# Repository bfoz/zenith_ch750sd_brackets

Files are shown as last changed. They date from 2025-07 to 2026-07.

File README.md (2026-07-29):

# Zenith CH750 Super Duty Brackets

Custom brackets that can be used to improve wire, cable, and hose routing.

## Fabrication

The various online cut shops have different ordering processes so you'll need to consult their documentation. 

If you're familiar with FreeCAD's Sheet Metal Workbench you can try using the "Unfold" feature to generate the flattened drawing files to send to the shop. 
However, exporting to a STEP file seems to produce more consistent results.

NOTE: As of June 2025, the unfolded files don't work well with [Send Cut Send](https://sendcutsend.com); use the STEP files instead.

## Wing Trailing Edge Bracket

The stock kit doesn't use the space inside of the wing trailing edge skins for very much.
If your build uses that space for a fuel return hose, or for the pitot and AoA hoses, you can use these brackets to help keep everything organized.

The file `TrailingEdgeBracket.FCStd` is a FreeCAD file containing several different bracket designs meant for different configurations of wiring and hoses in the left wing. 

The part named `OutboardTrailingEdgeBracket` is intended to hold the wires that go out to the wingtips and the slats (if you have those). 
You can either use 4 of these brackets for each wing and replace the ziptie anchors that came in the kit, or you can use one for each wing just inboard of the joiner bracket in the rear spar.
If you have a fuel return hose from your engine (ULPower etc), you'll want to use at least one of these (inboard of the joiner plate but outboard of the fuel hose) to help hold the wires off of that hose.

For the right wing, which doesn't have Pitot or AoA tubes, you can use `OutboardTrailingEdgeBracket` for the inboard brackets as well. 

To make the brackets for the right wing, you'll need to flip the bend angle for half of the parts. 
Alternatively, most cut shops that do online ordering will give you the option of duplicating the part with a reversed bend angle at order time.
You'll have two extra holes in the resulting right wing bracket because only the left wing has the pitot and AoA tubes. Feel free to use those holes for something else, or simply leave them unpopulated.

If you're using the braided fuel hoses from [Aircraft Specialty](https://www.aircraftspecialty.com) the part named `BushingsGrommets` should work well for you.

### Bushings and Grommets

Each bracket is meant to be used with snap bushings and grommets for holding the hoses and wires. 

These parts have been used successfully with fuel hoses from [Aircraft Specialty](https://www.aircraftspecialty.com) and the [Dynon pneumatic installation kit](https://shop.dynon.com/products/pitot-static-aoa-pneumatic-installation-kit):

- [1/4" ID Snap Bushings](https://www.amazon.com/dp/B00OP6070I) for 1/4" OD pitot and AoA hoses
- [1/2" ID AN931 Elastic Grommet](https://www.aircraftspruce.com/catalog/appages/an931.php) for the fuel return hose
- [1/4" ID AN931 Elastic Grommet](https://www.aircraftspruce.com/catalog/appages/an931.php) for the wingtip and landing light wires

If you're planning to use `OutboardTrailingEdgeBracket` outboard of the fuel hoses you'll likely need some 1/8" ID grommets for the wires. Either of these will fit:

- [1/8" ID Oil Resistant Buna-O Rubber Grommets](https://www.mcmaster.com/9307K35/)
- [1/8" ID High Temperature Silicone Rubber](https://www.mcmaster.com/1061T11/)

**NOTE:** The part named `OutboardTrailingEdgeBracketTape` is meant to be used with double sided tape. Be sure to get a strong tape that can handle extreme conditions. I used 3M VHB tape.

### Installation

1. Slide the brackets and grommets onto the fuel return hose first. You won't be able to that later.
2. The fuel return hoses grommets are a tight fit. Use a small flat screwdriver to force the grommets into the bracket around the hose. Be careful to not damage the grommets.
3. Push the 1/4" ID wire grommets into their respective holes
4. Snap the snap bushings into their holes
5. Cleco the brackets to the rear spar
6. Feed the pitot and AoA tubes through the snap bushings
7. Feed the wires through the wire grommets
8. Rivet the brackets once you're happy with everything

## Fuel Return Hose Bracket

`FuelReturnHoseBracket.FCStd`

If you're using a fuel return hose and routing it through the wing bay just outboard of the fuel tank, 
this bracket can be used to keep the hose from bouncing around inside of the wing.

The part in the file is for the left wing. Flip the bend angle to make the part for the right wing.

### Bushings and Grommets

- [1/2" ID AN931 Elastic Grommet](https://www.aircraftspruce.com/catalog/appages/an931.php) 

### Installation

- Use 2 A4 rivets to attach the bracket to the rear stiffener in the wing bay just outboard of the fuel tank. You will need to match drill holes in the stiffener.
- Position the bracket roughly in the middle of the stiffener, or wherever seems to be right for your fuel hose.
- The stiffening flange of the bracket should be outboard of the fuel hose to prevent the hose from rubbing on the flange. 

## Wingtip wire brackets

`WingtipWireBracket.FCStd`

If you run the wingtip wires through the outboard-most bay in the wing, this bracket will keep the wires from flopping around inside that bay.

**NOTE**: This bracket is currently sized for the 3-conductor wire that comes with the kit. I haven't yet tested it with the 4-conductor wire that most builders use.

### Bushings and Grommets

- [1/8" ID AN931 Elastic Grommet](https://www.aircraftspruce.com/catalog/appages/an931.php) 

### Installation

1. Align the bracket with the stiffener in the outobard-most bay of the wing
2. Match-drill the two rivet holes using a #30 drill bit
3. Rivet to the stiffener with 2 A4 rivets
4. Push the grommet into the hole
5. Feed the wires through the grommet

## Elevator Pulley Bracket

`ElevatorPulleyBracket.FCStd`

The stock kit uses nylon blocks as "pulleys" for the elevator control cables. Presumably, steel cables rubbing on plastic will eventually wear out the plastic, 
necessitating periodic replacement. If you'd like to avoid that problem, or at least delay it, you can install pulleys just forward of the jump seat rear channel 
that will keep the control cables from rubbing on the nylon.

### Fabrication

The CAD file includes two parts, `Bracket` and `Base`, that need to be fabricated. The other parts are only for reference. 

- Export the `Bracket` and `Base` parts as STEP files and send them to your favorite cut shop
- Use 1mm thick (0.040") Aluminum for both parts
- The CAD file uses the bend radius and K-factor for [Send Cut Send](https://sendcutsend.com). Adjust as needed for your shop.

### Parts

| Part Number | Quantity | Description |
|---|---|---|
| [MC20220-1](https://www.aircraftspruce.com/catalog/pnpages/MS20220-1.php) | 2 | 1.75" Phenolic Pulley |
| [AN5-13A](https://www.aircraftspruce.com/catalog/hapages/an5.php) | 2 | Bolt |
| [AN365-524A](https://www.aircraftspruce.com/pages/ha/nut_an365/an365_2.php) | 2 | Elastic Stop Nut |
| [AN960-516](https://www.aircraftspruce.com/catalog/hapages/flatwashers.php) | 4 | Washer |
| | | Tape (blue tape, electrical tape, whatever is handy)  |

### Installation

**NOTE**: The base plates can be installed on either the inside, or the outside, of the airplane. The cables will line up either way. The difference is purely aesthetic.

1. Run the control cables through the holes in the rear jump seat channel, tie weights to the ends, and adjust to approximate the final position of the cables
2. Set the base plate and pulley brackets on the cabin floor with the cables running through the brackets
3. Install the pulleys in the brackets (using the bolts, nuts, and washers) with the cables under the pulleys
4. Align the pulleys and brackets with the cables and make sure everything looks "right"
5. With the base plates under the brackets, and all of the rivet holes aligned, tape the base plates to the cabin floor skin
6. Remove the pulleys and brackets while leaving the base plate in place
7. Match drill the holes in the base plates through the cabin floor skin using a #20 drill bit
8. Debur the holes
9. Cleco the base plates and brackets in place. **NOTE**: The base plates can be installed on the inside or the outside of the airplane. The choice is purely aesthetic.
10. Rivet with A5 rivets **from the outisde** of the airplane
11. Re-install the pulleys with the control cables under the pulleys

## Matco Parking Brake Valve Bracket

`MatcoParkingBrakeBracket.FCStd`

The brake line kit from [Aircraft Specialty](https://www.aircraftspecialty.com/Superdutybrakes.html) doesn't come with any brackets for mounting the [Matco parking brake valve](https://matcoals.com/product/parking-brake-valve-dual/). 
The included hoses are cut to length assuming that you have the brackets that you can see in [Mark Pensenstadler's video](https://youtu.be/gur6rt8JNb0?si=d8QNzfhoa7Ir_gkw) 
(the kit was created to fit his airplane). Unfortunately, Mark made his brackets out of scrap aluminum and he didn't provide enough details 
to make your own, nor did he say anything about selling the brackets himself.

The brackets in this file are my attempt to replicate Mark's design. Although, I made the top piece overlap the bottom pieces because I think it looks better that way.
It will still work if you prefer it the other way.

I also switched the bottom mounting holes from A4 rivets to M4 bolts. Drilling rivet holes in the heel support plate traps shavings in a way that's very hard to clean out. 
It would be better to drill the holes before riveting the support plate, but that isn't always possible, or obvious ahead of time. 
Using M4 adhesive mounting studs is a much cleaner, and more expensive, option.

### Parts

| Part Number | Quantity  | Product Page | Description |
|---|---|---|---|
| Zenith Super Duty Brake kit | 1 | [Link](https://www.aircraftspecialty.com/Superdutybrakes.html) | Aircraft Specialty Zenith Super Duty Brake kit |
| 97590A711 | 4 | [McMaster-Carr](https://www.mcmaster.com/products/adhesive-mount-studs/thread-size~m4-1/) | Adhesive-Ready Studs, Zinc-Plated Steel, M4x 0.7mm Thread, 10mm Long, 23mm Diameter Base  |
| M4 Elastic Locking Nuts | 4 | | |
| Adhesive | | | JB Weld, Gorilla Expoxy, Scotch-Weld DP100FR, etc |

### Installation

1. Using A4 rivets, rivet the top piece to the bottom pieces to make it look like the assembly in the CAD file
2. The bases of the mounting studs will overlap. You'll need to trim about 5mm off one side of each. Test fit in the brackets to ensure clearance.
3. Clean the mounting area on the heel plate thoroughly to remove all dust, grease, oil, etc
3. Bolt the valve to the top plate. Make sure to install the bolt from the bottom. When the valve is installed, you should have the nuts and rubber washers on top.
4. Make sure the shiny end of the brake valve is pointing aft
5. Bolt the studs into the bottom of the bracket and tighten
6. Apply adhesive to the mounting side of each stud
7. **NOTE: This step is permanent!** Locate the bracket where you want it to be on the heel plate and press the studs onto the metal. **NOTE: This is permanent!**
8. Follow the adhesive manufacturer's instructions for set time, clamping pressure, etc

## Rudder Pedal Brackets

`RudderPedalBracketAssembly.FCStd`

The provided brackets are also used as bearings for the rudder pedals, but it's just a bare metal-on-metal surface. 
Because the pedals are steel, most builders either paint or powder coat them. Over time, the coating wears off and stops protecting the steel.
These brackets replace the aluminum brackets that came in your kit, and add a Delrin bushing to act as a bearing. 
The brackets' holes for the tubes have also been enlarged to avoid wearing on the tubes. 
The Delrin holes should be a snug fit for a powder coated pedal tube, and might be a little loose for a painted tube. Feel free to adjust the hole size if needed.

### Additional Parts

| Part Number | Quantity | Description |
|---|---|---|
| M5x16 Socket Head Screw  | 4 | Standard thread metric bolts. Other head shapes are acceptable. |
| M5 Washer | 8 | Washers for M5 bolts |
| M5 Lock Nut | 4 | Locking nuts for M5 bolts |

### Installation

1. Using the kit-provided hardware, bolt each bracket to the cabin floor skins in the normal fashion. *NOTE* The upper bolts interfere with installing the lower bolts.
2. Using the metric hardware, bolt the Delrin pieces to the inboard side of each bracket. Use washers under the heads and the nuts
3. Slide the rudder tubes into the brackets from the inboard side

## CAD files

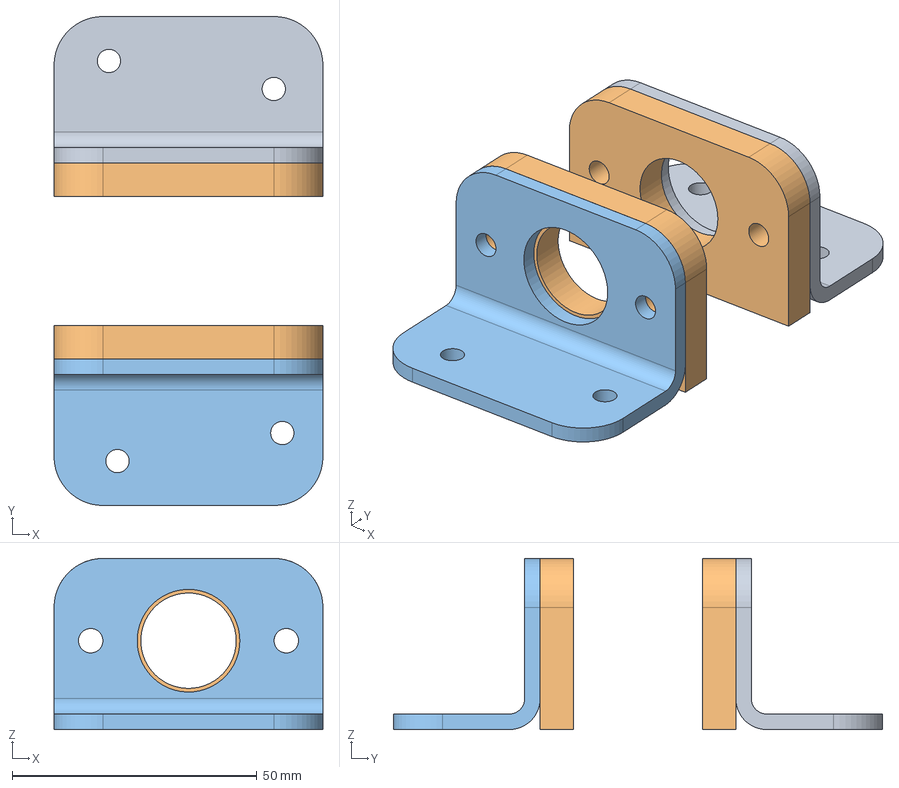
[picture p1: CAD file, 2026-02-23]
RudderPedalBracketAssembly.FCStd
55.0 x 100.0 x 35.0 mm
LeftBracket
Bearing x 2
RightBracket

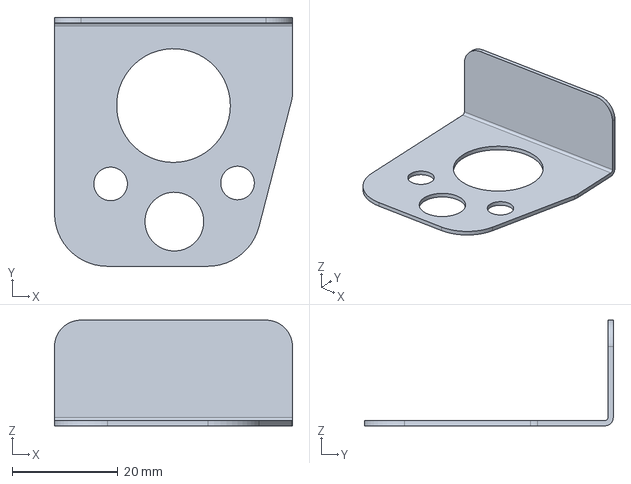
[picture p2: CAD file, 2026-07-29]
TrailingEdgeBracket.FCStd
45.0 x 47.0 x 20.0 mm

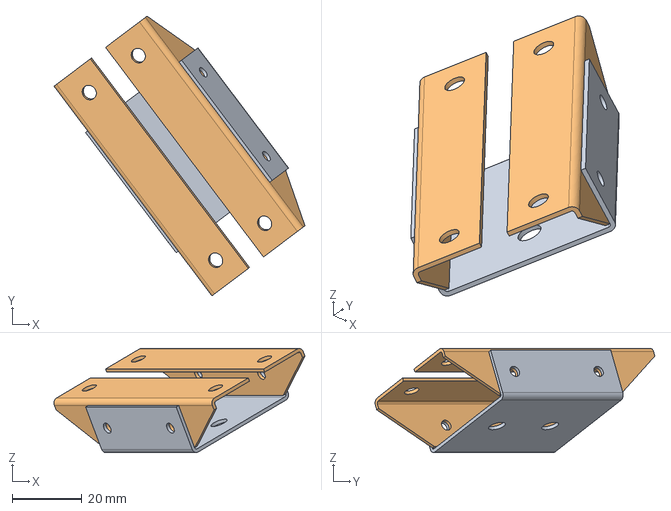
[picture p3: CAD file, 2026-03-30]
MatcoParkingBrakeBracket.FCStd
71.7 x 79.9 x 29.7 mm
Top Bracket
Bottom Bracket x 2

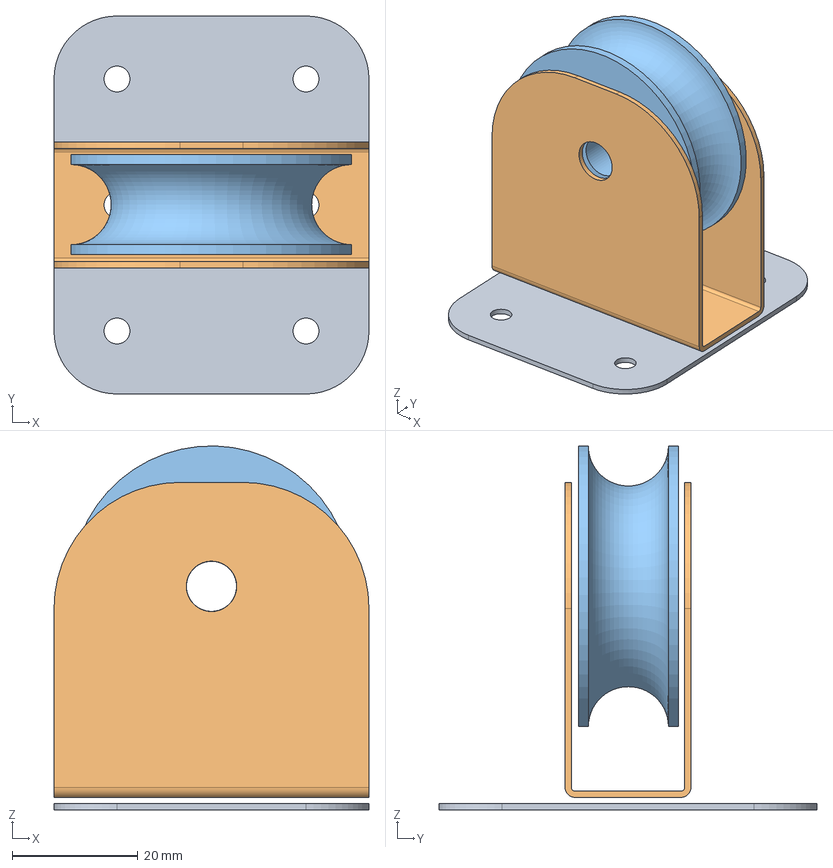
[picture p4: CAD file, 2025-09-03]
ElevatorPulleyBracket.FCStd
50.0 x 60.0 x 57.8 mm
Base
Bracket
Pulley

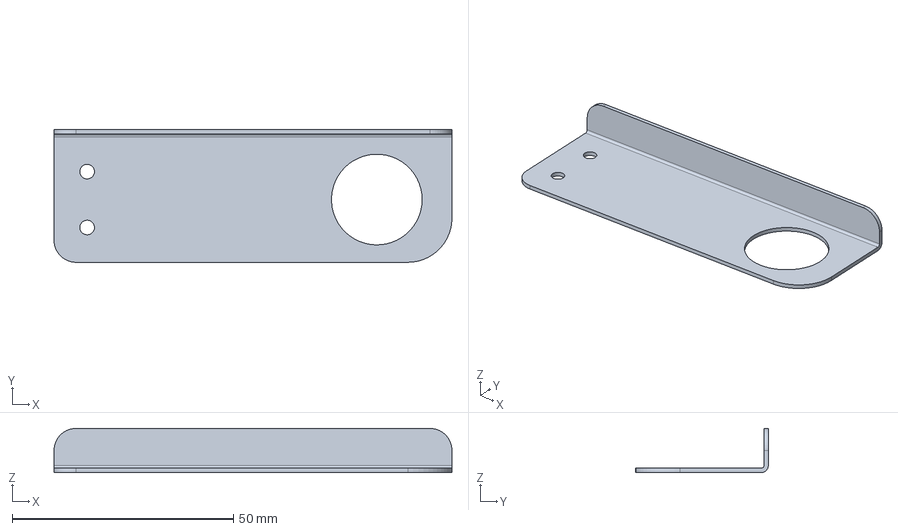
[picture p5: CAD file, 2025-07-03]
FuelReturnHoseBracket.FCStd
90.0 x 30.0 x 10.0 mm

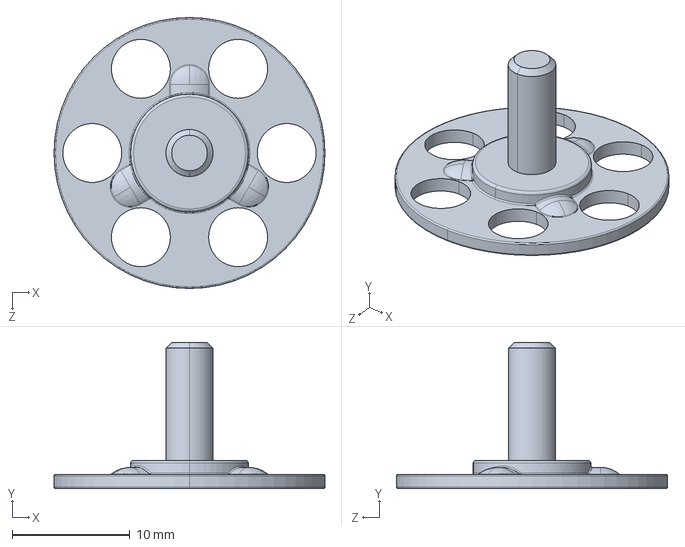
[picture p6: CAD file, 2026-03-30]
mcmaster/97590A711_NO THREADS_Adhesive-Ready Studs.STEP
23.0 x 12.4 x 23.0 mm

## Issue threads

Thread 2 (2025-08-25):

Fix the grommet hole size in the XX bracket

bfoz, 2025-08-25:

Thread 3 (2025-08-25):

Create a bracket for the elevator pulleys

bfoz, 2025-08-25:
- The pulleys are part number [MC20220-1](https://www.aircraftspruce.com/catalog/appages/phenolicpulleys.php).
- The bracket attaches to the cabin floor just forward of where the elevator pulleys pass through the rear jump seat channel
- Two brackets need to be installed, one for each of the elevator cables
- Update the README with installation instructions

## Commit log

2025-06-30 Added the wing trailing edge bracket
    [TrailingEdgeBracket.FCStd]
2025-07-02 Moved the Fabrication section
    It isn't necessarily specific to any particular bracket
2025-07-02 Added a bracket for the fuel return hose
    [FuelReturnHoseBracket.FCStd]
2025-07-03 Fixed the bend radius for the fuel return hose bracket to match Send Cut Send
    [FuelReturnHoseBracket.FCStd]
2025-07-03 Added a bracket for the wingtip wires
    [TrailingEdgeBracket.FCStd]
2025-09-03 [#3] Added mounting brackets for the elevator control cable pulleys
    [ElevatorPulleyBracket.FCStd]
2025-10-31 [#4] Added a bracket for the Matco parking brake valve
    [MatcoParkingBrakeBracket.FCStd]
2026-02-23 Added brackets for the rudder pedals
    [RudderPedalBracketAssembly.FCStd]
2026-03-30 Recomputed for FreeCAD 1.1
    [MatcoParkingBrakeBracket.FCStd]
2026-03-30 Changed the Matco parking brake bracket bottom mounting holes to M4
    Using A4 rivets, or any rivets, requires drilling holes in the heel support plate, which traps the shavings. Switching to adhesive backed M4 studs is a better option.
    [MatcoParkingBrakeBracket.FCStd]
2026-03-30 Added adhesive-ready studs to the parking brake assembly and updated the installation instructions
    [97590A711_NO THREADS_Adhesive-Ready Studs.STEP]
2026-07-29 Updated the trailing edge bracket for FreeCAD v1.1
    [TrailingEdgeBracket.FCStd]
2026-07-29 Added OutboardTrailingEdgeBracket and OutboardTrailingEdgeBracketTape
    [TrailingEdgeBracket.FCStd]
2026-10-13 Added the wingtip wire bracket document
    WingtipWireBracket.FCStd was described in the README since 6863d6b but the
    model itself was never committed, so the bracket could not be fabricated from
    the repository.
2026-10-14 Added notes on the Sheet Metal add-on dependency and proxy data loss
    Corrects an earlier claim: the add-on installs to
    ~/Library/Application Support/FreeCAD/v1-1/Mod/sheetmetal, not .../FreeCAD/Mod,
    so its absence from the latter path means nothing. Documents open cleanly with
    the add-on installed and BaseShape.Proxy restores as a live SMBaseShape.
    Also records that a document opened while the add-on is missing loses the
    feature's module reference on save and cannot be repaired by installing the
    add-on afterwards, so a document that logs "blocked import of module
    'SheetMetalBaseShapeCmd'" must be closed without saving. Documents the exact,
    limited scope of the damage in WingtipWireBracket.F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
2026-10-14 Saved WingtipWireBracket again
    No idea what, if anything, changed
2026-10-17 Added a bracket for mounting the ELT next to the rear access panel
2026-10-17 Lowered the pulley location for the elevator pulley bracket
    The pulley needs to be closer to the bottom skin to pull the cable down far enough to keep it from rubbing
2026-10-22 Removed the superseded root STEP files and corrected the documentation
    Deleted the 12 hand-made STEP files at the repository root and the 3 in
    RudderPedalAssembly/, which are all superseded by the generated step/
    directory. 14 of the 15 are reproduced identically by make. The last one,
    TrailingEdgeBracket-BodyBushingsGrommets_Unfold.step, had no manifest
    equivalent, but its hand-made DXF and SVG siblings are still present
    untracked, and the BushingsGrommets body itself still exports as
    TrailingEdgeBracket-BushingsGrommets.step, so nothing needed to order the
    part is gone. All 15 were untracked, so this deletes no history.
    These were all untracked, so the deletions themselves are not part of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
2026-10-23 Named the two release assets as a FreeCAD and STEP pair
    The v1 release shipped zenith_ch750sd_brackets.zip next to
    zenith_ch750sd_brackets-v1-steps.zip. Those are the same base name, and the
    only thing telling a builder which file to hand the cut shop was a version
    string. They now publish as -FreeCAD.zip and -STEP.zip.
    STEP rather than steps, because the suffix names the file format. It also
    matches the rest of the repository, which already says step-files everywhere:
    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
2026-10-23 Updated the remote URL for the renamed repository
    Renamed to zenith_ch750sd. Several upcoming additions are not brackets, and
    dropping the noun rather than replacing it avoids both the stale claim and the
    plurality problem a substitute noun would have reintroduced.
    origin now points at git@github.com:bfoz/zenith_ch750sd.git. GitHub redirects
    the old URL, so existing clones and the v0 and v1 release assets are
    unaffected. The release bundles follow the new name automatically because they
    derive from github.event.repository.name, and the hardcoded
    zenith-ch750sd-step-files artifact name happens to match the repository in its
    hyphenated form, so nothing else needs to change.
2026-10-24 Updated AGENTS.md for the repository rename and the current working tree
    Corrected documentation drift found after renaming the repository to zenith_ch750sd:
    - Recorded that v1.0.1 is the first tag to ship the paired -FreeCAD.zip / -STEP.zip assets, verified against the live release. Deleted a stray v0.1 tag that was left over from an interactive rebase; it pointed at a fixup commit whose content is already in main, and its tree was identical to v0.
    - Dropped the *.dxf and *.svg unfold drawings from the deliverables, the derived-filename rule and the scratch inventory; they were hand-made, never tracked, and are no longer kept in the tree. Removed the test.pdf/test1.pdf entries for the same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
